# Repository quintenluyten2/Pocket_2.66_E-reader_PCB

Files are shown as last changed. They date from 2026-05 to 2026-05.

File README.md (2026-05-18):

# Pocket 2.66 — E-reader PCB

A compact e-reader PCB built around a 2.13"/2.66" e-ink display and the ESP32-C3FH4 microcontroller.

<p align="center">
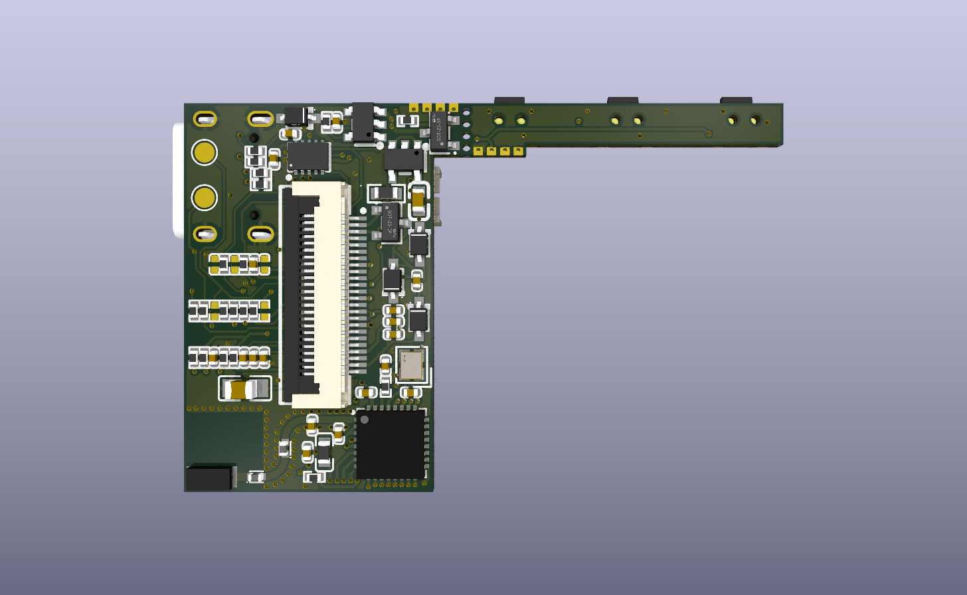
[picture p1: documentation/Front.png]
PCB Front
  
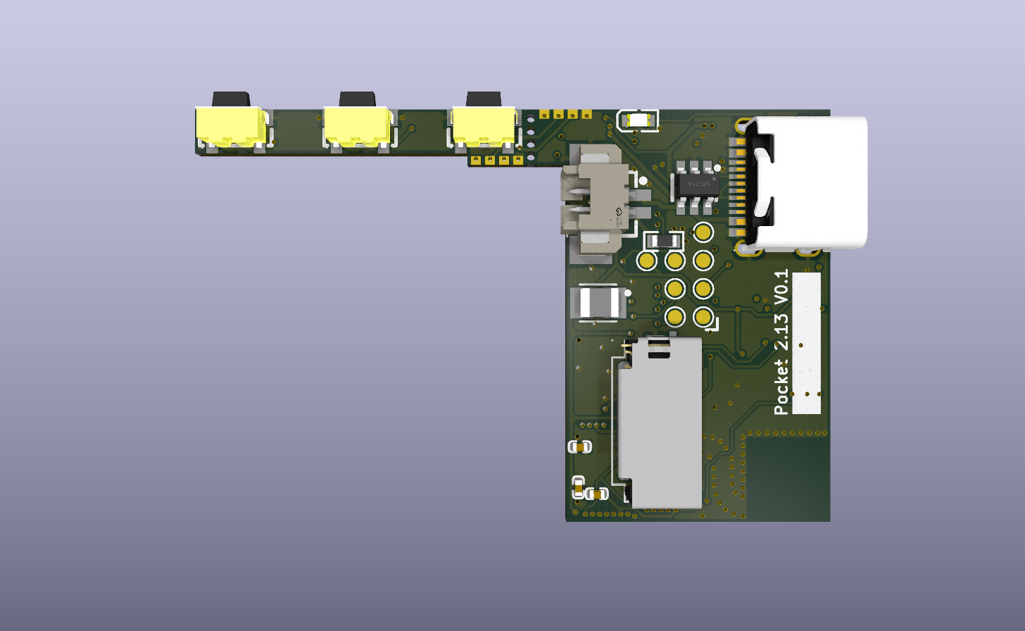
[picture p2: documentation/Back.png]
PCB Back
  
</p>

## Features

- **MCU:** ESP32-C3FH4 (RISC-V, 2.4 GHz Wi-Fi + BLE, 4 MB flash)
- **Display:** 2.13"/2.66" e-ink, connected via 24-pin FPC
- **Power:** USB-C input, single-cell Li-Po with GX4054 charger and BQ27220 fuel gauge
- **Storage:** micro-SD card slot
- **Connectivity:** On-board SMD 2.4 GHz antenna (Not yet matched to 35 Ohm)
- **Form factor:** 4-layer 1 mm PCB, min trace 0.12 mm, min via 0.3/0.4 mm (designed for JLCPCB)

## Repository contents

```
├── Pocket 2.66.kicad_sch       Schematic
├── Pocket 2.66.kicad_pcb       PCB layout
├── Pocket 2.66.kicad_pro       KiCad project file
├── Pocket 2.66.kicad_dru       Design rules
├── libs/lcsc/.                 Component Library
├── documentation/
│   ├── Pocket 2.66 BOM with MPN.csv   Schematic BOM
│   ├── Pocket 2.66 Interactive.html   Interactive PCB BOM
│   ├── PCB.stl
│   └── V0_schematic_review.pdf
└── production/
    ├── Pocket_2.66.zip         Gerber + drill files for fabrication
    ├── bom.csv                 JLCPCB BOM (for PCBA)
    ├── positions.csv           JLCPCB pick-and-place (for PCBA)
    └── netlist.ipc
```

## Additional parts
To make an E-reader, you need this PCB fully assembled, and:
- **Display** 24-pin 2.13"/2.66" Black/White E-ink display (e.g. Waveshare)
- **Battery** 803450 1500 mAh battery for 2.66" version or 802540 800 mAh battery for 2.13" version. Use 1.25 mm 2P Picoblade connector
- **Housing** 3D printing files coming soon

## Key components

| Ref | Part | Description |
|-----|---|---|
| U1 | ESP32-C3FH4 | Main MCU |
| U2 | LCK-TF-027H30008-WLG | Push-pull micro-SD slot |
| U3 | GX4054 | Li-Po charger |
| U4 | GS2019-33TR5 | 3.3 V LDO |
| U5 | BQ27220YZFR | Battery fuel gauge |
| U6 | SRV05-4-P-T7 | USB ESD protection |
| P1 | USB-TYPE-C-018 | USB-C connector |
| P3 | FPC-05F-24PH20 | 24-pin FPC for e-ink display |
| ANT2 | H2U38D1E1B0100 | 2.4 GHz SMD antenna |
| X1 | XL7EL89CLI-111YLC-40M | 40 MHz crystal |

## Opening the project

1. Open **KiCad 8** or later.
2. File → Open Project → select `Pocket 2.66.kicad_pro`.
3. The component library is self-contained in `libs/lcsc/`. The project's `fp-lib-table` and `sym-lib-table` already point to it, so no additional setup is needed.
4. Set the `KICAD_LCSC_3D_MODEL_DIR` path variable to `${KIPRJMOD}/libs/lcsc/3dmodels` for 3D models to appear (Preferences → Configure Paths).

## Production files

Ready-to-order Gerber files are in `production/Pocket_2.66.zip`. The BOM and pick-and-place files are formatted for JLCPCB PCBA.

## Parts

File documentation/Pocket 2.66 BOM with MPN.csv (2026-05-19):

Reference | Qty | Value | DNP | Footprint | Manufacturer | LCSC | Description | MPN | LCSC Type
ANT2 | 1 | 2.45 Ghz 1206 |  | LCSC:SMD_ANT_1206 | Unictron | C6569546 | Unictron H2U38D1E1B0100 | H2U38D1E1B0100
C0,C19,C22,C24 | 4 | 4.7uF 10V |  | LCSC:C0402 | Samsung Electro-Mechanics | C23733 | 4.7uF (475) ±20% 10V | CL05A475MP5NRNC
C1,C2,C3,C4,C5,C6,C7,C11,C12,C13,C14,C15,C18,C20 | 14 | 1uF |  | LCSC:C0402 | Samsung Electro-Mechanics | C52923 | 1uF (105) ±10% 25V | CL05A105KA5NQNC
C8 | 1 | 4.7uF 25V |  | LCSC:C1779_C0805 | Samsung Electro-Mechanics | C1779 | 4.7uF (475) ±10% 25V | CL21A475KAQNNNE
C10 | 1 | 0.7pF 0402 |  | LCSC:C0402 | muRata | C397301 | GJM1555C1HR70WB01D | GJM1555C1HR70WB01D
C16,C17 | 2 | 15pF |  | LCSC:C0402 | FH | C1548 | 15pF (150) ±5% 50V | 0402CG150J500NT
C21 | 1 | 22uF |  | LCSC:C59461_C0603 | Samsung Electro-Mechanics | C59461 | CL10A226MQ8NRNC | CL10A226MQ8NRNC
D1,D2,D3,D20 | 4 | Schottky SOD-323 |  | LCSC:C191023_SOD-323_L1_8-W1_3-LS2_5-RD | Guangdong Hottech | C191023 | 1N5819WS | 1N5819WS
D4 | 1 | RED |  | LCSC:C2286_LED0603-RD | Hubei KENTO Elec | C2286 | 0603 | KT-0603R
FB1 | 1 | BLM18PG121SN1D_C14709 |  | LCSC:C14709_L0603 | muRata | C14709 | BLM18PG121SN1D_C14709 | BLM18PG121SN1D
L1 | 1 | 22uH 600mA |  | LCSC:C48689518_L1008 | SOREDE | C48689518 | SRTC.252010.YB220MT00 | SRTC.252010.YB220MT00
L2 | 1 | 8.2nH 0402 |  | LCSC:L0402 | muRata | C84404 | LQW15AN8N2G00D | LQW15AN8N2G00D
L3 | 1 | 1.6nH 0402 |  | LCSC:L0402 | muRata | C341686 | LQW15AN1N6C00D | LQW15AN1N6C00D
P1 | 1 | USB-TYPE-C-018 |  | LCSC:C2927038_USB-C_SMD-TYPE-C-31-M-12 | DEALON | C2927038 | USB-TYPE-C-018 | USB-TYPE-C-018
P3 | 1 | FPC-05F-24PH20 |  | LCSC:C2856805_FPC-SMD_24P-P0_50_FPC-05F-24PH20 | XUNPU | C2856805 | FPC-05F-24PH20 | FPC-05F-24PH20
P4 | 1 | HX-1.25-2AWB |  | LCSC:C52016406_CONN-SMD_2P-P1_25_HX-1_25-2AWB | hanxia | C52016406 | HX-1.25-2AWB | HX-1.25-2AWB
Q1 | 1 | HL2300 |  | LCSC:SOT23-3 | R+O | C7420343 | HL2300_C7420343 | HL2300
Q2 | 1 | HL2305 |  | LCSC:SOT23-3 | R+O | C28646261 | HL2305 | HL2305
R1 | 1 | 2.2Ω |  | LCSC:R0603 | UNI-ROYAL | C22939 | 2.2Ω (2R20) ±1% | 0603WAF220KT5E
R2,R5,R8,R11,R12,R13,R14,R15,R16,R17,R19,R23 | 12 | 10KΩ |  | LCSC:R0402 | UNI-ROYAL | C25744 | 10KΩ (1002) ±1% | 0402WGF1002TCE
R6,R7,R18 | 3 | 22Ω |  | LCSC:R0402 | UNI-ROYAL | C25092 | 22Ω (22R0) ±1% | 0402WGF220JTCE
R9,R10 | 2 | 5.1KΩ |  | LCSC:R0402 | UNI-ROYAL | C25905 | 5.1KΩ (5101) ±1% | 0402WGF5101TCE
R20,R21,R22 | 3 | 2KΩ |  | LCSC:R0402 | UNI-ROYAL | C4109 | 2KΩ (2001) ±1% | 0402WGF2001TCE
SH2 | 1 | 25mΩ |  | LCSC:R0603 | YAGEO | C859739 | 25mΩ 0603 ±1% | RL0603FR-070R025L
SW1,SW2,SW3 | 3 | TS-24CA-S16 |  | LCSC:C42420265_SW-SMD_L4_7-W3_5-P3_35-EH | JXTCONN | C42420258 | TS-24CA-S26 | TS-24CA-S16
U1 | 1 | ESP32-C3FH4 |  | LCSC:C2858491_QFN-32_L5_0-W5_0-P0_50-TL-EP3_7 | ESPRESSIF | C2858491 | ESP32-C3FH4 | ESP32-C3FH4
U2 | 1 | LCK-TF-027H30008-WLG |  | LCSC:C50380692_TF-SMD_HYCW104-TF08-375B | LCKELEC | C50380692 | LCK-TF-027H30008-WLG | LCK-TF-027H30008-WLG
U3 | 1 | GX4054 |  | LCSC:SOT-23-5 | GUOXIN JIAPIN SEMICONDUCTOR | C5259235 | GX4054 | GX4054
U4 | 1 | GS2019-33TR5 |  | LCSC:SOT-23-5 | Gainsil | C41419378 | GS2019-33TR5 | GS2019-33TR5
U5 | 1 | STC3115AIQT |  | LCSC:C2688637_DFN-10_L3_0-W2_0-P0_50-BL | ST Microelectronics | C2688637 | STC3115AIQT | STC3115AIQT
U6 | 1 | ESD-USB |  | LCSC:C85364_SOT-23-6_L2_9-W1_6-P0_95-LS2_8-BR | PROTEK | C85364 | SRV05-4-P-T7 | SRV05-4-P-T7
X1 | 1 | 40MHz 9pF 2016 |  | LCSC:C49304717_CRYSTAL-SMD_4P-L2_0-W1_6-BL | YXC Crystal Oscillators | C49304717 | XL7EL89CLI-111YLC-40M | XL7EL89CLI-111YLC-40M

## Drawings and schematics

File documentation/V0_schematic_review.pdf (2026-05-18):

# 1uF GND

# SCK USBD+

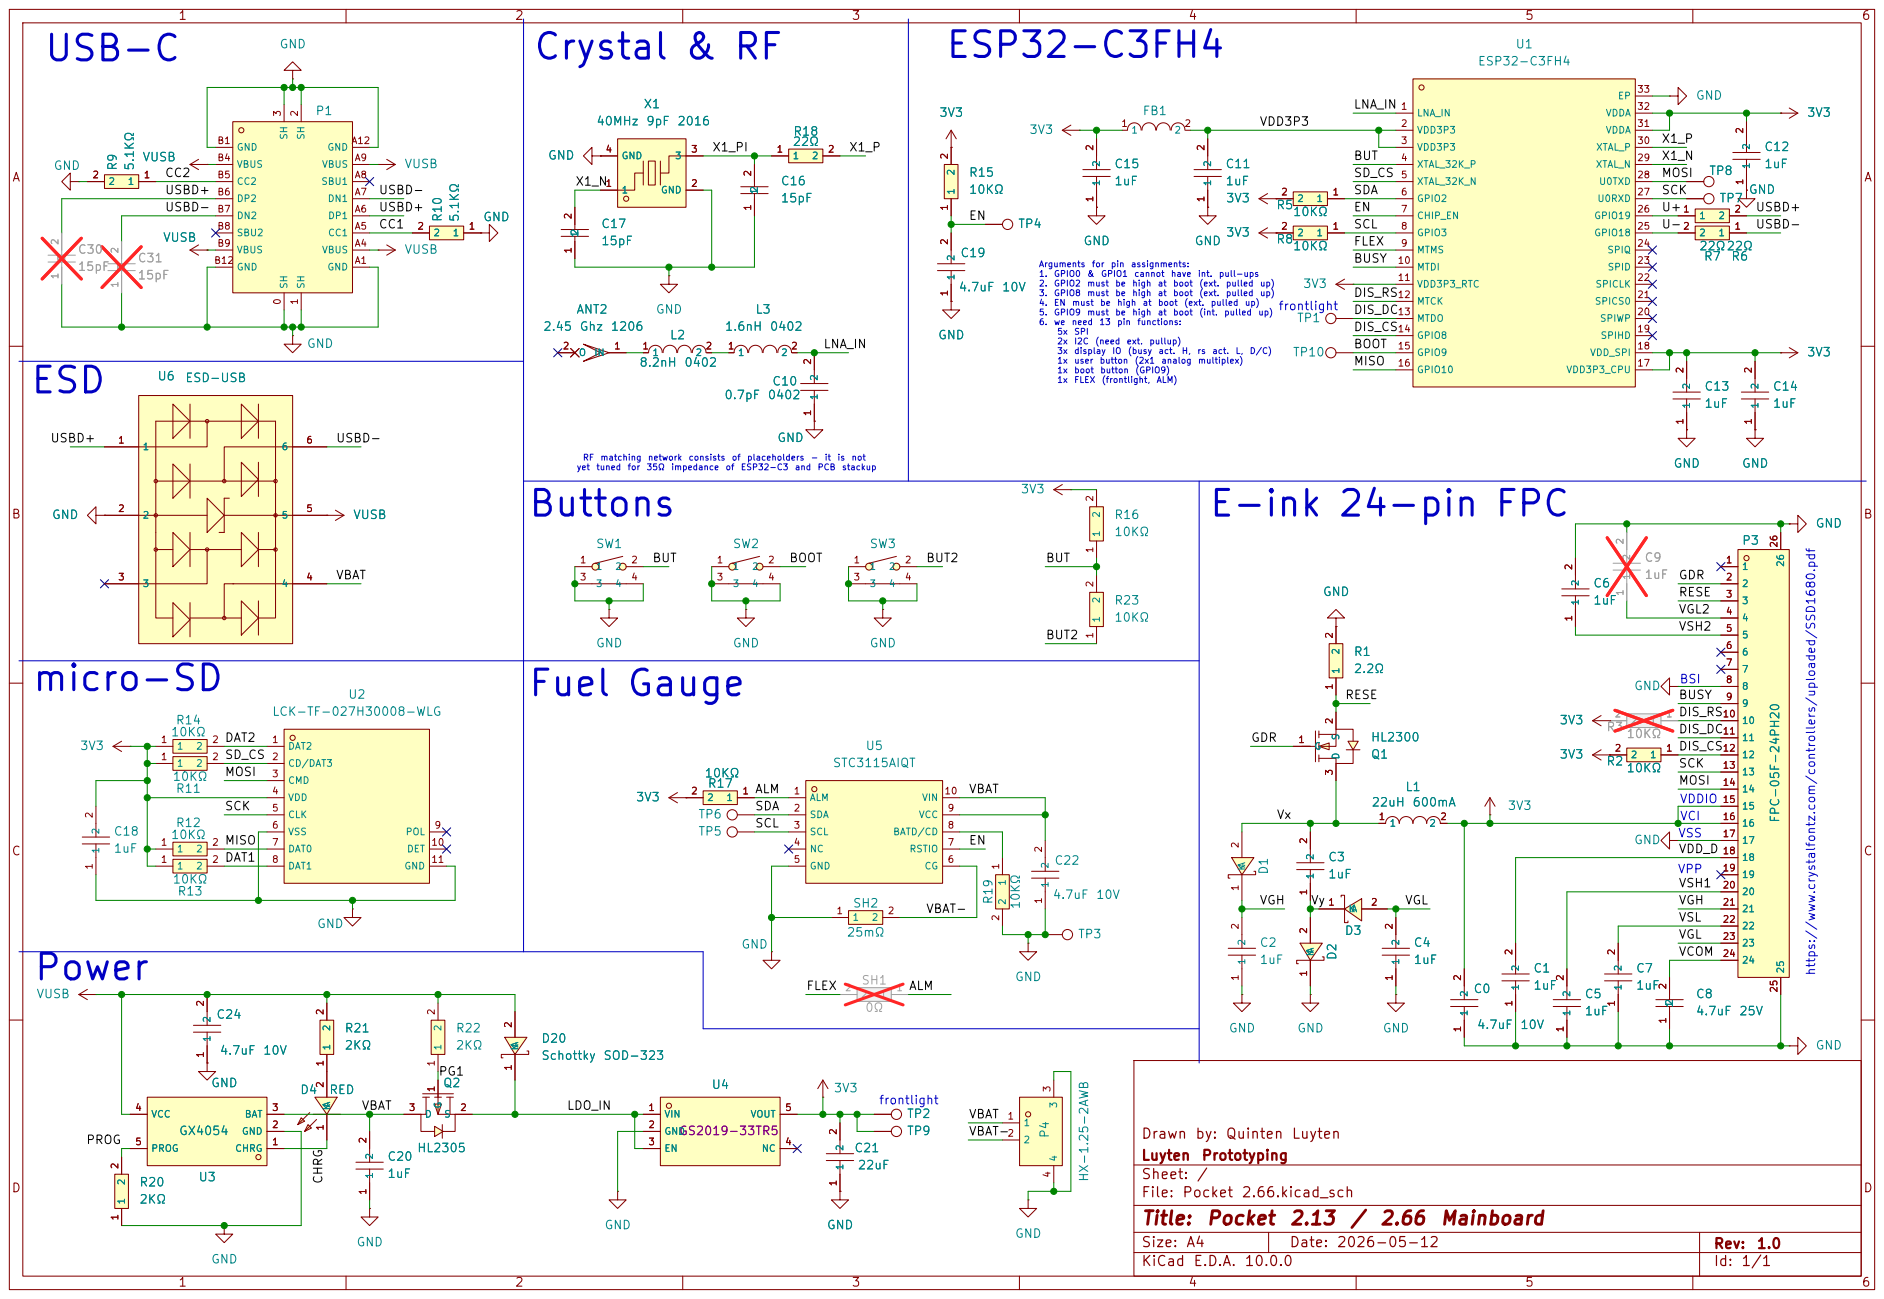
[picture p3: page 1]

2 GND VUSB U6 ESD-USB

RF matching network consists of placeholders - it is not
yet tuned for 35Ω impedance of ESP32⁻C3 and PCB stackup
Buttons

Drawn by: Quinten Luyten
Luyten Prototyping
Sheet: /
D Date: 2026⁻05⁻12 KiCad E.D.A. 10.0.0
File: Pocket 2.66.kicad_sch
Title: Pocket 2.13 / 2.66 Mainboard

### Pocket 2.66 BOM with MPN

Reference | Qty | Value | DNP | Footprint | Manufacturer | LCSC | Description | JLC Type | MPN
ANT2 | 1 | 2.45 Ghz 1206 | | LCSC:SMD_ANT_1206 | Unictron | C6569546 | Unictron H2U38D1E1B0100 | Extended | H2U38D1E1B0100
C0,C19,C22,C24 | 4 | 4.7uF 10V | | LCSC:C0402 | Samsung Electro-Mechanics | C23733 | 4.7uF (475) ±20% 10V | | CL05A475MP5NRNC
C1,C2,C3,C4,C5,C6,C7,C11,C12,C13,C14,C15,C18,C20 | 14 | 1uF | | LCSC:C0402 | Samsung Electro-Mechanics | C52923 | 1uF (105) ±10% 25V | | CL05A105KA5NQNC
C8 | 1 | 4.7uF 25V | | LCSC:C1779_C0805 | Samsung Electro-Mechanics | C1779 | 4.7uF (475) ±10% 25V | | CL21A475KAQNNNE
C9 | 1 | 1uF | DNP | LCSC:C0402 | Samsung Electro-Mechanics | C52923 | 1uF (105) ±10% 25V | | CL05A105KA5NQNC
C10 | 1 | 0.7pF 0402 | | LCSC:C0402 | muRata | C397301 | GJM1555C1HR70WB01D | Extended | GJM1555C1HR70WB01D
C16,C17 | 2 | 15pF | | LCSC:C0402 | FH | C1548 | 15pF (150) ±5% 50V | | 0402CG150J500NT
C21 | 1 | 22uF | | LCSC:C59461_C0603 | Samsung Electro-Mechanics | C59461 | CL10A226MQ8NRNC | | CL10A226MQ8NRNC
C30,C31 | 2 | 15pF | DNP | LCSC:C0402 | FH | C1548 | 15pF (150) ±5% 50V | | 0402CG150J500NT
D1,D2,D3,D20 | 4 | Schottky SOD-323 | | LCSC:C191023_SOD-323_L1_8-W1_3-LS2_5-RD | Guangdong Hottech | C191023 | 1N5819WS | | 1N5819WS
D4 | 1 | RED | | LCSC:C2286_LED0603-RD | Hubei KENTO Elec | C2286 | 603 | Basic | KT-0603R
FB1 | 1 | BLM18PG121SN1D_C14709 | | LCSC:C14709_L0603 | muRata | C14709 | BLM18PG121SN1D_C14709 | | BLM18PG121SN1D
L1 | 1 | 22uH 600mA | | LCSC:C48689518_L1008 | SOREDE | C48689518 | SRTC.252010.YB220MT00 | | SRTC.252010.YB220MT00
L2 | 1 | 8.2nH 0402 | | LCSC:L0402 | muRata | C84404 | LQW15AN8N2G00D | Extended | LQW15AN8N2G00D
L3 | 1 | 1.6nH 0402 | | LCSC:L0402 | muRata | C341686 | LQW15AN1N6C00D | Extended | LQW15AN1N6C00D
P1 | 1 | USB-TYPE-C-018 | | LCSC:C2927038_USB-C_SMD-TYPE-C-31-M-12 | DEALON | C2927038 | USB-TYPE-C-018 | Extended | USB-TYPE-C-018
P3 | 1 | FPC-05F-24PH20 | | LCSC:C2856805_FPC-SMD_24P-P0_50_FPC-05F-24PH20 | XUNPU | C2856805 | FPC-05F-24PH20 | Extended | FPC-05F-24PH20
P4 | 1 | HX-1.25-2AWB | | LCSC:C52016406_CONN-SMD_2P-P1_25_HX-1_25-2AWB | hanxia | C52016406 | HX-1.25-2AWB | Extended | HX-1.25-2AWB
Q1 | 1 | HL2300 | | LCSC:SOT23-3 | R+O | C7420343 | HL2300_C7420343 | Promotional | HL2300
Q2 | 1 | HL2305 | | LCSC:SOT23-3 | R+O | C28646261 | HL2305 | Promotional | HL2305
R1 | 1 | 2.2Ω | | LCSC:R0603 | UNI-ROYAL | C22939 | 2.2Ω (2R20) ±1% | | 0603WAF220KT5E
R2,R5,R8,R11,R12,R13,R14,R15,R16,R17,R19,R23 | 12 | 10KΩ | | LCSC:R0402 | UNI-ROYAL | C25744 | 10KΩ (1002) ±1% | | 0402WGF1002TCE
R3 | 1 | 10KΩ | DNP | LCSC:R0402 | UNI-ROYAL | C25744 | 10KΩ (1002) ±1% | | 0402WGF1002TCE
R6,R7,R18 | 3 | 22Ω | | LCSC:R0402 | UNI-ROYAL | C25092 | 22Ω (22R0) ±1% | Basic | 0402WGF220JTCE
R9,R10 | 2 | 5.1KΩ | | LCSC:R0402 | UNI-ROYAL | C25905 | 5.1KΩ (5101) ±1% | | 0402WGF5101TCE
R20,R21,R22 | 3 | 2KΩ | | LCSC:R0402 | UNI-ROYAL | C4109 | 2KΩ (2001) ±1% | | 0402WGF2001TCE
SH2 | 1 | 25mΩ | | LCSC:R0603 | YAGEO | C859739 | 25mΩ 0603 ±1% | Extended | RL0603FR-070R025L
SW1,SW2,SW3 | 3 | TS-24CA-S16 | | LCSC:C42420265_SW-SMD_L4_7-W3_5-P3_35-EH | JXTCONN | C42420258 | TS-24CA-S26 | Extended | TS-24CA-S16
U1 | 1 | ESP32-C3FH4 | | LCSC:C2858491_QFN-32_L5_0-W5_0-P0_50-TL-EP3_7 | ESPRESSIF | C2858491 | ESP32-C3FH4 | Extended | ESP32-C3FH4
U2 | 1 | LCK-TF-027H30008-WLG | | LCSC:C50380692_TF-SMD_HYCW104-TF08-375B | LCKELEC | C50380692 | LCK-TF-027H30008-WLG | Extended | LCK-TF-027H30008-WLG
U3 | 1 | GX4054 | | LCSC:SOT-23-5 | GUOXIN JIAPIN SEMICONDUCTOR | C5259235 | GX4054 | Extended | GX4054
U4 | 1 | GS2019-33TR5 | | LCSC:SOT-23-5 | Gainsil | C41419378 | GS2019-33TR5 | Extended | GS2019-33TR5
U5 | 1 | STC3115AIQT | | LCSC:C2688637_DFN-10_L3_0-W2_0-P0_50-BL | ST Microelectronics | C2688637 | STC3115AIQT | Extended | STC3115AIQT
U6 | 1 | ESD-USB | | LCSC:C85364_SOT-23-6_L2_9-W1_6-P0_95-LS2_8-BR | PROTEK | C85364 | SRV05-4-P-T7 | Promotional | SRV05-4-P-T7
X1 | 1 | 40MHz 9pF 2016 | | LCSC:C49304717_CRYSTAL-SMD_4P-L2_0-W1_6-BL | YXC Crystal Oscillators | C49304717 | XL7EL89CLI-111YLC-40M | | XL7EL89CLI-111YLC-40M

1

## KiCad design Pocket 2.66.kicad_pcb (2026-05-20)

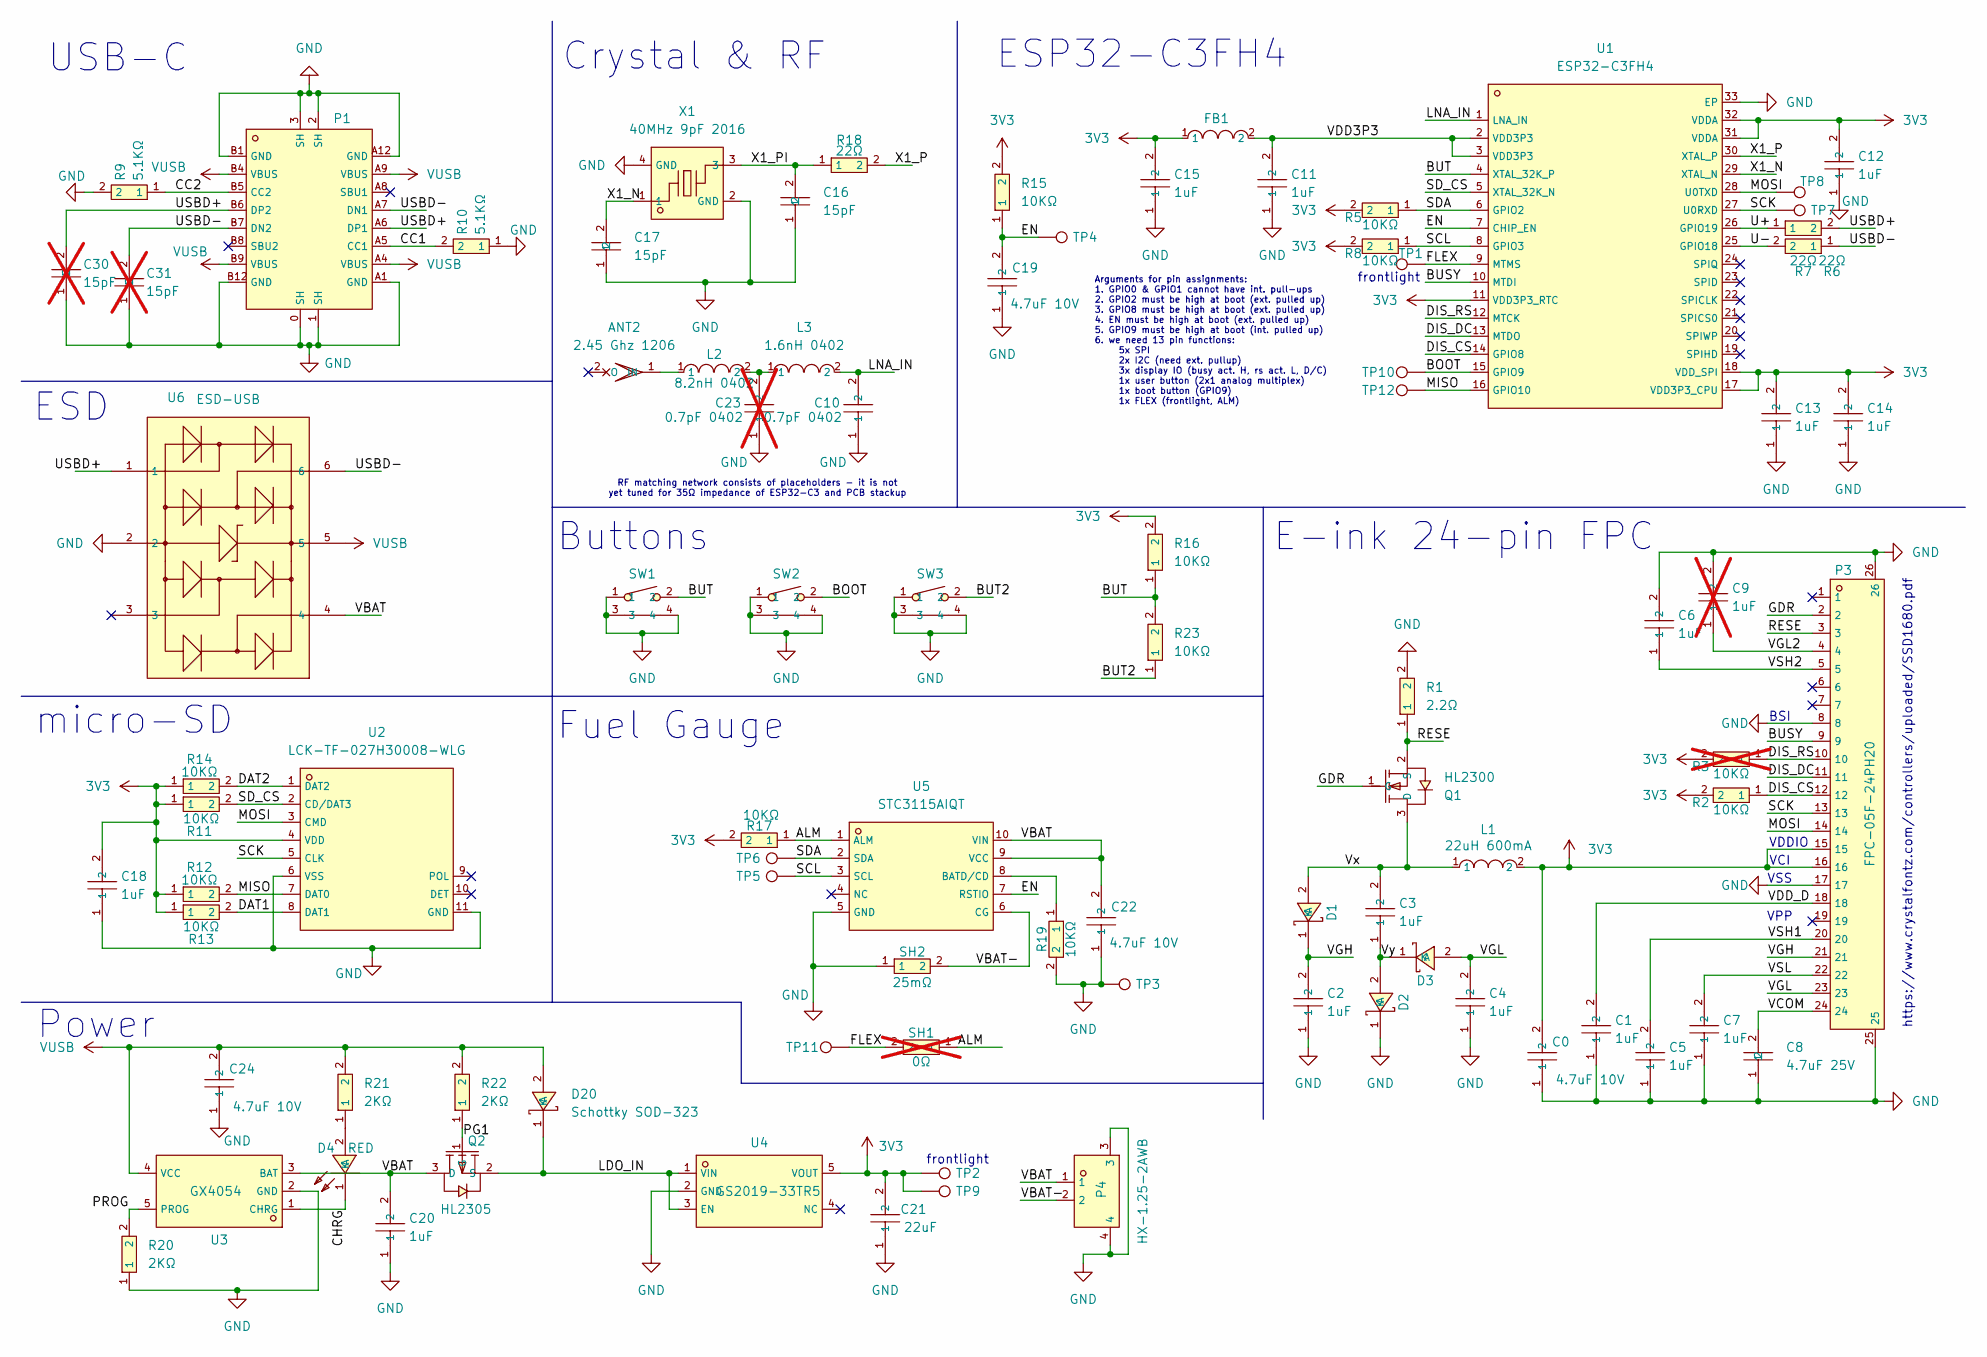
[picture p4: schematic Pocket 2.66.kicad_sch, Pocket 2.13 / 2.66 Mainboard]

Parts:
ANT2: 2.45 Ghz 1206; SMD_ANT_1206; MPN H2U38D1E1B0100; LCSC C6569546
C0, C19, C22, C24: 4.7uF 10V; C0402; MPN CL05A475MP5NRNC; LCSC C23733
C1, C2, C3, C4, C5, C6, C7, C11, C12, C13, C14, C15, C18, C20: 1uF; C0402; MPN CL05A105KA5NQNC; LCSC C52923
C8: 4.7uF 25V; C1779_C0805; MPN CL21A475KAQNNNE; LCSC C1779
C9: 1uF; C0402; MPN CL05A105KA5NQNC; LCSC C52923; not fitted
C10: 0.7pF 0402; C0402; MPN GJM1555C1HR70WB01D; LCSC C397301
C16, C17: 15pF; C0402; MPN 0402CG150J500NT; LCSC C1548
C21: 22uF; C59461_C0603; MPN CL10A226MQ8NRNC; LCSC C59461
C23: 0.7pF 0402; C0402; MPN GJM1555C1HR70WB01D; LCSC C397301; not fitted
C30, C31: 15pF; C0402; MPN 0402CG150J500NT; LCSC C1548; not fitted
D1, D2, D3, D20: Schottky SOD-323; C191023_SOD-323_L1_8-W1_3-LS2_5-RD; MPN 1N5819WS; LCSC C191023
D4: RED; C2286_LED0603-RD; MPN KT-0603R; LCSC C2286
FB1: BLM18PG121SN1D_C14709; C14709_L0603; MPN BLM18PG121SN1D; LCSC C14709
L1: 22uH 600mA; C48689518_L1008; MPN SRTC.252010.YB220MT00; LCSC C48689518
L2: 8.2nH 0402; L0402; MPN LQW15AN8N2G00D; LCSC C84404
L3: 1.6nH 0402; L0402; MPN LQW15AN1N6C00D; LCSC C341686
P1: USB-TYPE-C-018; C2927038_USB-C_SMD-TYPE-C-31-M-12; MPN USB-TYPE-C-018; LCSC C2927038
P3: FPC-05F-24PH20; C2856805_FPC-SMD_24P-P0_50_FPC-05F-24PH20; MPN FPC-05F-24PH20; LCSC C2856805
P4: HX-1.25-2AWB; C52016406_CONN-SMD_2P-P1_25_HX-1_25-2AWB; MPN HX-1.25-2AWB; LCSC C52016406
Q1: HL2300; SOT23-3; MPN HL2300; LCSC C7420343
Q2: HL2305; SOT23-3; MPN HL2305; LCSC C28646261
R1: 2.2Ω; R0603; MPN 0603WAF220KT5E; LCSC C22939
R2, R5, R8, R11, R12, R13, R14, R15, R16, R17, R19, R23: 10KΩ; R0402; MPN 0402WGF1002TCE; LCSC C25744
R3: 10KΩ; R0402; MPN 0402WGF1002TCE; LCSC C25744; not fitted
R6, R7, R18: 22Ω; R0402; MPN 0402WGF220JTCE; LCSC C25092
R9, R10: 5.1KΩ; R0402; MPN 0402WGF5101TCE; LCSC C25905
R20, R21, R22: 2KΩ; R0402; MPN 0402WGF2001TCE; LCSC C4109
SH1: 0Ω; R0402; not fitted
SH2: 25mΩ; R0603; MPN RL0603FR-070R025L; LCSC C859739
SW1, SW2, SW3: TS-24CA-S16; C42420265_SW-SMD_L4_7-W3_5-P3_35-EH; MPN TS-24CA-S16; LCSC C42420258
TP1, TP2: TestPoint; TestPoint_Pad_D1.5mm
TP3, TP4, TP5, TP6, TP7, TP8, TP9, TP10, TP11, TP12: TestPoint; TestPoint_Pad_D1.0mm
U1: ESP32-C3FH4; C2858491_QFN-32_L5_0-W5_0-P0_50-TL-EP3_7; MPN ESP32-C3FH4; LCSC C2858491
U2: LCK-TF-027H30008-WLG; C50380692_TF-SMD_HYCW104-TF08-375B; MPN LCK-TF-027H30008-WLG; LCSC C50380692
U3: GX4054; SOT-23-5; MPN GX4054; LCSC C5259235
U4: GS2019-33TR5; SOT-23-5; MPN GS2019-33TR5; LCSC C41419378
U5: STC3115AIQT; C2688637_DFN-10_L3_0-W2_0-P0_50-BL; MPN STC3115AIQT; LCSC C2688637
U6: ESD-USB; C85364_SOT-23-6_L2_9-W1_6-P0_95-LS2_8-BR; MPN SRV05-4-P-T7; LCSC C85364
X1: 40MHz 9pF 2016; C49304717_CRYSTAL-SMD_4P-L2_0-W1_6-BL; MPN XL7EL89CLI-111YLC-40M; LCSC C49304717

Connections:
3V3: C0.2, C12.2, C13.2, C14.2, C15.2, C18.2, C21.2, FB1.1, L1.2, P3.15, P3.16, R2.2, R3.2, R5.2, R8.2, R11.1, R12.1, R13.1, R14.1, R15.2, R16.2, R17.2, TP2.1 (1_1), TP9.1 (1_1), U1.11 (VDD3P3_RTC), U1.17 (VDD3P3_CPU), U1.18 (VDD_SPI), U1.31 (VDDA), U1.32 (VDDA), U2.4 (VDD), U4.5 (VOUT)
/ALM: R17.1, SH1.1, U5.1 (ALM)
/BOOT: SW2.2, TP10.1 (1_1), U1.15 (GPIO9)
/BUSY: P3.9, U1.10 (MTDI)
/BUT: R16.1, R23.2, SW1.2, U1.4 (XTAL_32K_P)
/BUT2: R23.1, SW3.2
/CC1: P1.A5 (CC1), R10.2
/CC2: P1.B5 (CC2), R9.1
/CHRG: D4.1 (K), U3.1 (CHRG)
/DAT1: R13.2, U2.8 (DAT1)
/DAT2: R14.2, U2.1 (DAT2)
/DIS_CS: P3.12, R2.1, U1.14 (GPIO8)
/DIS_DC: P3.11, U1.13 (MTDO)
/DIS_RS: P3.10, R3.1, U1.12 (MTCK)
/EN: C19.2, R15.1, TP4.1 (1_1), U1.7 (CHIP_EN), U5.7 (RSTIO)
/FLEX: SH1.2, TP1.1 (1_1), TP11.1 (1_1), U1.9 (MTMS)
/GDR: P3.2, Q1.1 (G)
/LDO_IN: D20.1 (K), Q2.2 (S), U4.1 (VIN), U4.3 (EN)
/LNA_IN: C10.2, L3.2, U1.1 (LNA_IN)
/MISO: R12.2, TP12.1 (1_1), U1.16 (GPIO10), U2.7 (DAT0)
/MOSI: P3.14, TP8.1 (1_1), U1.28 (U0TXD), U2.3 (CMD)
/PG1: Q2.1 (G), R22.1
/PROG: R20.2, U3.5 (PROG)
/RESE: P3.3, Q1.2 (S), R1.1
/SCK: P3.13, TP7.1 (1_1), U1.27 (U0RXD), U2.5 (CLK)
/SCL: R8.1, TP5.1 (1_1), U1.8 (GPIO3), U5.3 (SCL)
/SDA: R5.1, TP6.1 (1_1), U1.6 (GPIO2), U5.2 (SDA)
/SD_CS: R11.2, U1.5 (XTAL_32K_N), U2.2 (CD/DAT3)
/U+: R6.1, U1.26 (GPIO19)
/U-: R7.2, U1.25 (GPIO18)
/USBD+: C30.2, P1.A6 (DP1), P1.B6 (DP2), R6.2, U6.1
/USBD-: C31.2, P1.A7 (DN1), P1.B7 (DN2), R7.1, U6.6
/VBAT: C20.2, C22.2, P4.1, Q2.3 (D), U3.3 (BAT), U5.9 (VCC), U5.10 (VIN), U6.4
/VBAT-: P4.2, SH2.2, U5.6 (CG)
/VCOM: C8.2, P3.24
/VDD3P3: C11.2, FB1.2, U1.2 (VDD3P3), U1.3 (VDD3P3)
/VDD_D: C1.2, P3.18
/VGH: C2.2, D1.1 (K), P3.21
/VGL: C4.2, D3.2 (A), P3.23
/VGL2: C9.1, P3.4
/VSH1: C5.2, P3.20
/VSH2: C6.1, P3.5
/VSL: C7.2, P3.22
/Vx: C3.2, D1.2 (A), L1.1, Q1.3 (D)
/Vy: C3.1, D2.2 (A), D3.1 (K)
/X1_N: C17.2, U1.29 (XTAL_N), X1.1
/X1_P: R18.2, U1.30 (XTAL_P)
/X1_PI: C16.2, R18.1, X1.3
GND: C0.1, C1.1, C2.1, C4.1, C5.1, C6.2, C7.1, C8.1, C9.2, C10.1, C11.1, C12.1, C13.1, C14.1, C15.1, C16.1, C17.1, C18.1, C19.1, C20.1, C21.1, C22.1, C23.1, C24.1, C30.1, C31.1, D2.1 (K), P1.0 (SH), P1.1 (SH), P1.2 (SH), P1.3 (SH), P1.A1 (GND), P1.A12 (GND), P1.B1 (GND), P1.B12 (GND), P3.8, P3.17, P3.25, P3.26, P4.3, P4.4, R1.2, R9.2, R10.1, R19.2, R20.1, SH2.1, SW1.1, SW1.3, SW1.4, SW2.1, SW2.3, SW2.4, SW3.1, SW3.3, SW3.4, TP3.1 (1_1), U1.33 (EP), U2.6 (VSS), U2.11 (GND), U3.2 (GND), U4.2 (GND), U5.5 (GND), U6.2, X1.2 (GND), X1.4 (GND)
unnamed: ANT2.1 (IN_1), L2.1
unnamed: C23.2, L2.2, L3.1
unnamed: D4.2 (A), R21.1
unnamed: R19.1, U5.8 (BATD/CD)
VUSB: C24.2, D20.2 (A), P1.A4 (VBUS), P1.A9 (VBUS), P1.B4 (VBUS), P1.B9 (VBUS), R21.2, R22.2, U3.4 (VCC), U6.5

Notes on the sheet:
Power
https://www.crystalfontz.com/controllers/uploaded/SSD1680.pdf
BSI
VCI
VPP
frontlight
Buttons
micro-SD
VSS
Arguments for pin assignments: 1. GPIO0 & GPIO1 cannot have int. pull-ups 2. GPIO2 must be high at boot (ext. pulled up) 3. GPIO8 must be high at boot (ext. pulled up) 4. EN must be high at boot (ext. pulled up) 5. GPIO9 must be high at boot (int. pulled up) 6. we need 13 pin functions: 5x SPI 2x I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
USB-C
Crystal & RF
RF matching network consists of placeholders - it is not yet tuned for 35Ω impedance of ESP32-C3 and PCB stackup
ESP32-C3FH4
E-ink 24-pin FPC
Fuel Gauge
ESD
VDDIO

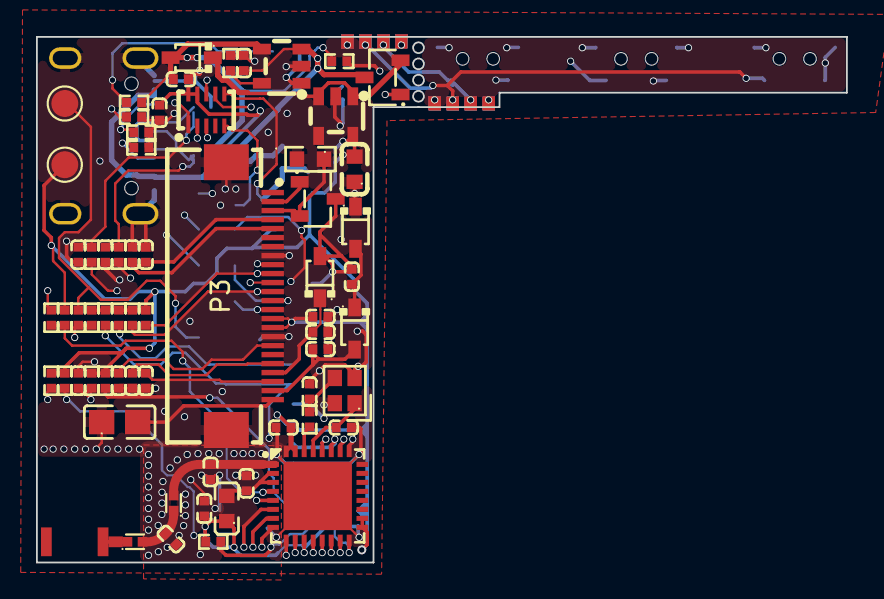
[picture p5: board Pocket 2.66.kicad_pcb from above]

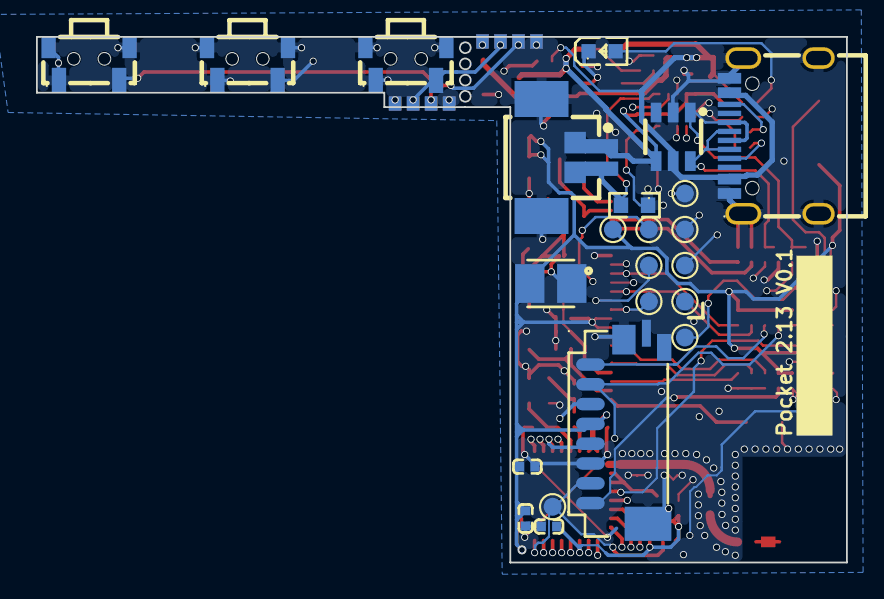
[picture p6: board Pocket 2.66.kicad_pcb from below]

Board: 4 copper layers, 45.0 x 29.2 mm, 88 parts (23 on the bottom side), 54 nets.

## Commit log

2026-05-18 Update RF on schematic and BOM details
    [Pocket 2.66 BOM with MPN.csv, Pocket 2.66.kicad_pcb, Pocket 2.66.kicad_sch]
2026-05-18 Move 2R2 basic part to top side
    [Pocket 2.66.kicad_pcb, Pocket 2.66.kicad_sch, positions.csv]
2026-05-18 remove vias from serial no. area
    [Pocket 2.66.kicad_pcb]
2026-05-18 Add PCB images to README and update gitignore
2026-05-19 Add extra test pads
    [Pocket 2.66.kicad_pcb, Pocket 2.66.kicad_sch, designators.csv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]
2026-05-19 Add second RF shunt (DNP) for extra matching flexibility
    [Pocket 2.66 BOM with MPN.csv, Pocket 2.66.kicad_pcb, Pocket 2.66.kicad_sch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]
2026-05-20 Remove floating traces
    [Pocket 2.66.kicad_pcb]
2026-05-23 Add 7 new library entries with MPN, Manufacturer, and LCSC Type
    - SOT-23-L generic footprint (clone of SOT23-3)
    - AO3400 NMOS (C20634976, FOSAN) → SOT-23-L
    - AO3401-ED PMOS (C4748724, HXY MOSFET) → SOT23-3
    - LCK-TF-027H37508-WLG SD slot (C50380694, LCKELEC) → C50380692 footprint
    - 2.2Ω 0402 ±1% (C2909330, FOJAN)
    - 47kΩ 0402 ±1% (C2906872, FOJAN)
    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
2026-05-23 Remove incorrect SOT-23-L footprint (clone of SOT23-3)
2026-05-23 Add SOT-23-L footprint and 3D models from C20634976
2026-05-23 Add SD103AWS-L symbol (C41376466) and rename LCSC Type to JLC Type
    - New symbol SD103AWS-L SOD-323 (C41376466, PIELENST) with same
    SOD-323 footprint/pinout as C191023, JLC Type: Extended
    - Rename all "LCSC Type" properties to "JLC Type" in 5 symbol files
    and 77 occurrences in the schematic
    [Pocket 2.66.kicad_sch]
